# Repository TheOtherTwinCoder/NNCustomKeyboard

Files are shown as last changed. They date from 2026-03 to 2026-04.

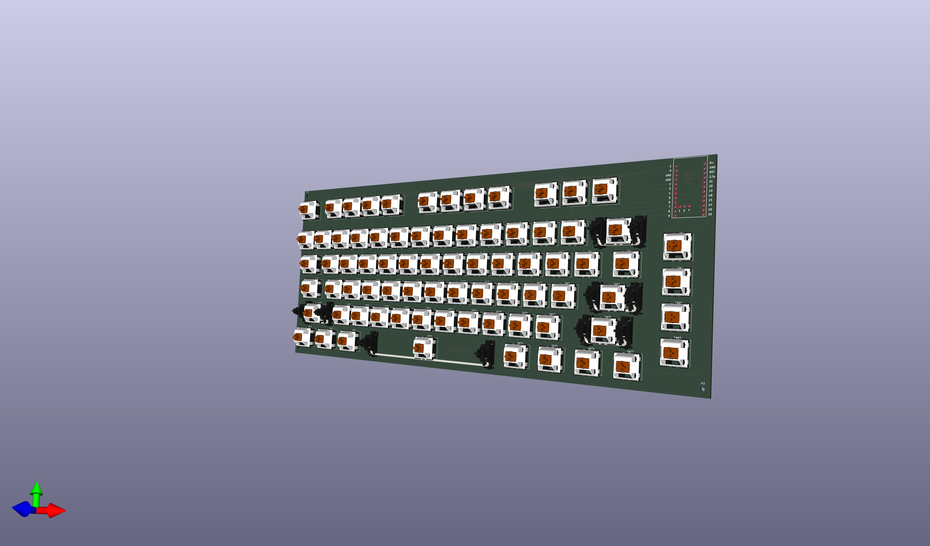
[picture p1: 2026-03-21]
3DFiles/3DPCB.png

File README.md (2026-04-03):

[Sponsored by AIVON](https://www.aivon.com/?code=K7)

# NNCustomKeyboard
I love keyboards, but they're not all that great - so let me make my own one something custom, so it's mine and something useful, so it's more practical than a traditional one!

## Look here first!

Here's my Github's sitemap:
3D Files - includes 3D file of PCB (STEP and an image), and its case

Production - includes Gerber Files, BOM, AND PNP/CPL files for PCB Fabrication

Projectfiles - includes .kicad_pcb, .kicad_sch, and .kicad_pro files to open PCB in KiCad

Links (MD file) - includes resources to build this project

README (MD file) - includes images of the PCB, the CSV file of BOM, and Assembly Instructions!

Thank you, Hack Club, AMD, Blueprint, and AIVON!

## Onshape Link

https://cad.onshape.com/documents/c9928b6a9f4ef1bbd20ca445/w/38d45bd75b935af33784f8b5/e/9c69ae00eee7f366adcabbe1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

## Full Assembly

Screenshot 2026-03-22 at 12 18 09 PM

## The V2 PCB:



## The PCB Schematic:



## Wiring Schematic

Screenshot 2026-03-16 at 1 09 35 PM

## BOM

| Items | Cost | Links | 
| :---: | :---: | :--- |
| Alpha Keys | $2.77 | (https://www.aliexpress.us/item/3256805792312994.html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) |
| PCB | $39 | Order using Gerber Files in the production folder :), this is a JLCPCB estimate, not including shipping. |
| Nice-Nano | $25 | https://typeractive.xyz/products/nice-nano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 |
| Battery | $8 | https://t.ly/81SML |
| Switches | $30 | https://mechanicalkeyboards.com/checkouts/cn/hWNA2r5NHFXzy1tke3oyGLrU/en/information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|
| Stabilizers | $1 | https://www.keychron.com/products/keychron-gold-plated-pcb-mounted-stabilizer-set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 |
| Grand Total | $138 | Submitting for review on Mar 21st!!! :) |

## Assembly

1. Since PCBA already assembled the diodes, we can skip this step. However, if no PCBA, solder on the diodes manually.
2. Solder on the AliExpress switches (found in the BOM).
3. Solder on Nice!Nano (BOM), and solder battery (BOM) to B+ and B- pins.
4. 3D Print the Case, located in STEP3D
5. Take the assembled PCB and slot it into the case
6. Solder on the rgb controller to the nice!nano, and the light strip to the controller.
7. Follow the instructions in [this video](https://www.youtube.com/watch?v=O_urj-rF3bQ)
8. That's it :)

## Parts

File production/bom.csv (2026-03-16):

Designator | Footprint | Quantity | Value | LCSC Part #
D1, D10, D11, D12, D13, D14, D15, D16, D17, D18, D19, D2, D20, D21, D22, D23, D24, D25, D26, D27, D28, D29, D3, D30, D31, D32, D33, D34, D35, D36, D37, D38, D39, D4, D40, D41, D42, D43, D44, D45, D46, D47, D48, D49, D5, D50, D51, D52, D53, D54, D55, D56, D57, D58, D59, D6, D60, D61, D62, D63, D64, D65, D66, D67, D68, D69, D7, D70, D71, D72, D73, D74, D75, D76, D77, D8, D9 | D_SOD-123F | 77 | D
SW1, SW10, SW11, SW12, SW13, SW14, SW15, SW16, SW17, SW18, SW19, SW2, SW20, SW21, SW22, SW23, SW24, SW25, SW27, SW29, SW3, SW30, SW31, SW32, SW33, SW34, SW35, SW36, SW37, SW38, SW39, SW4, SW40, SW42, SW44, SW45, SW46, SW47, SW48, SW49, SW5, SW50, SW51, SW52, SW53, SW54, SW56, SW58, SW59, SW6, SW60, SW61, SW62, SW63, SW64, SW65, SW66, SW67, SW69, SW7, SW8, SW9 | SW_Cherry_MX_PCB_1.00u | 62 | SW_Push
SW26 | SW_Cherry_MX_PCB_2.00u | 1 | SW_Push
SW28, SW41 | SW_Cherry_MX_PCB_1.50u | 2 | SW_Push
SW43 | SW_Cherry_MX_PCB_1.75u | 1 | SW_Push
SW55, SW57 | SW_Cherry_MX_PCB_2.25u | 2 | SW_Push
SW68 | SW_Cherry_MX_PCB_2.75u | 1 | SW_Push
SW70, SW71, SW72, SW74, SW75, SW76, SW77 | SW_Cherry_MX_PCB_1.25u | 7 | SW_Push
SW73 | SW_Cherry_MX_PCB_6.25u | 1 | SW_Push
U1 | Nice_Nano_V2 | 1 | Nice_Nano_V2

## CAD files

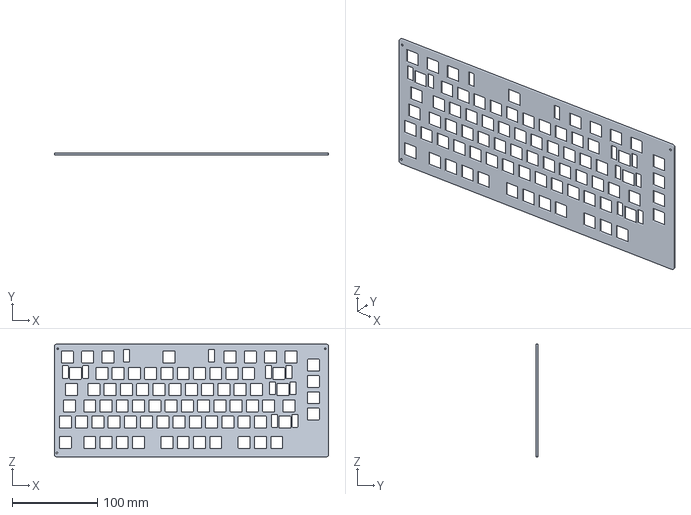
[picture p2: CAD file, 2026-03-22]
3DFiles/NewPlate.step
321.0 x 2.00 x 132.1 mm

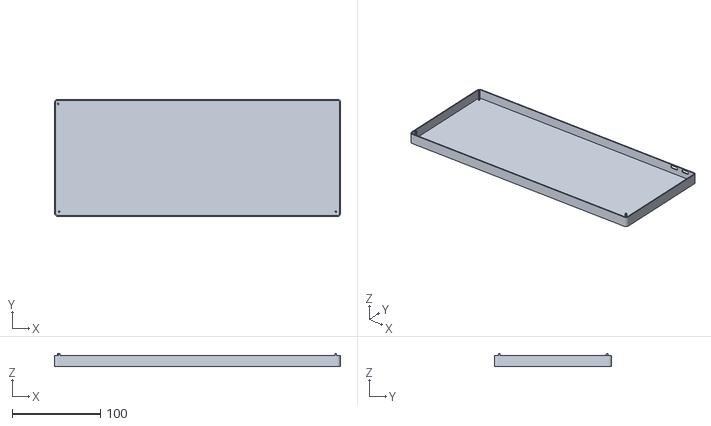
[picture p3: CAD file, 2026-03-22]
3DFiles/CaseNoPlate.stl
323.9 x 132.9 x 14.8

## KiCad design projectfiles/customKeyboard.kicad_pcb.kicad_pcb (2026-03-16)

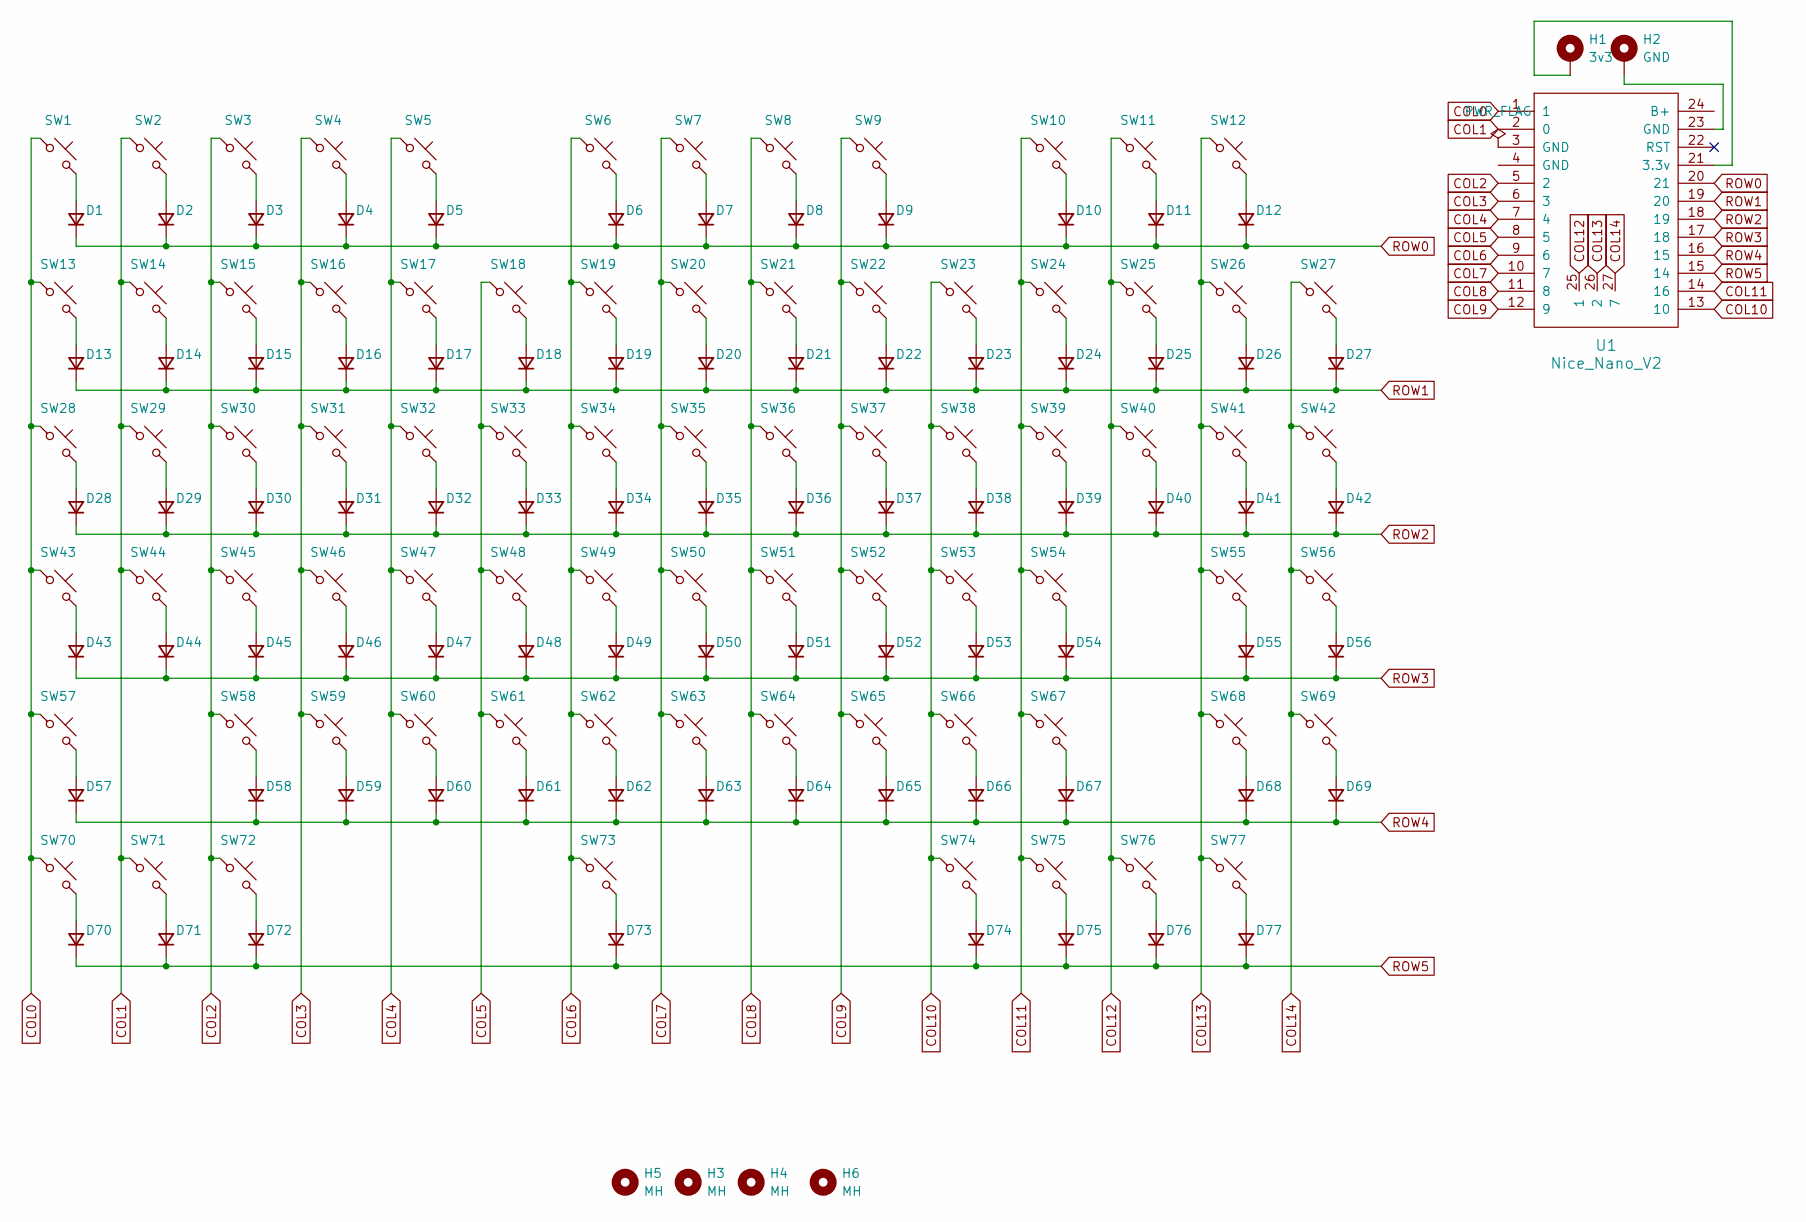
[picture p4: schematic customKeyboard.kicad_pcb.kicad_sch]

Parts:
D1, D2, D3, D4, D5, D6, D7, D8, D9, D10, D11, D12, D13, D14, D15, D16, D17, D18, D19, D20, D21, D22, D23, D24, D25, D26, D27, D28, D29, D30, D31, D32, D33, D34, D35, D36, D37, D38, D39, D40, D41, D42, D43, D44, D45, D46, D47, D48, D49, D50, D51, D52, D53, D54, D55, D56, D57, D58, D59, D60, D61, D62, D63, D64, D65, D66, D67, D68, D69, D70, D71, D72, D73, D74, D75, D76, D77: D; D_SOD-123
H1: 3v3; MountingHole_2.2mm_M2
H2: GND; MountingHole_2.2mm_M2
H3, H4, H5, H6: MH; MountingHole_2.2mm_M2
SW1, SW2, SW3, SW4, SW5, SW6, SW7, SW8, SW9, SW10, SW11, SW12, SW13, SW14, SW15, SW16, SW17, SW18, SW19, SW20, SW21, SW22, SW23, SW24, SW25, SW27, SW29, SW30, SW31, SW32, SW33, SW34, SW35, SW36, SW37, SW38, SW39, SW40, SW42, SW44, SW45, SW46, SW47, SW48, SW49, SW50, SW51, SW52, SW53, SW54, SW56, SW58, SW59, SW60, SW61, SW62, SW63, SW64, SW65, SW66, SW67, SW69: SW_Push; SW_Cherry_MX_PCB_1.00u
SW26: SW_Push; SW_Cherry_MX_PCB_2.00u
SW28, SW41: SW_Push; SW_Cherry_MX_PCB_1.50u
SW43: SW_Push; SW_Cherry_MX_PCB_1.75u
SW55, SW57: SW_Push; SW_Cherry_MX_PCB_2.25u
SW68: SW_Push; SW_Cherry_MX_PCB_2.75u
SW70, SW71, SW72, SW74, SW75, SW76, SW77: SW_Push; SW_Cherry_MX_PCB_1.25u
SW73: SW_Push; SW_Cherry_MX_PCB_6.25u
U1: Nice_Nano_V2

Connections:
COL0: SW1.1, SW13.1, SW28.1, SW43.1, SW57.1, SW70.1, U1.1
COL1: SW2.1, SW14.1, SW29.1, SW44.1, SW71.1, U1.2 (0)
COL2: SW3.1, SW15.1, SW30.1, SW45.1, SW58.1, SW72.1, U1.5 (2)
COL3: SW4.1, SW16.1, SW31.1, SW46.1, SW59.1, U1.6 (3)
COL4: SW5.1, SW17.1, SW32.1, SW47.1, SW60.1, U1.7 (4)
COL5: SW18.1, SW33.1, SW48.1, SW61.1, U1.8 (5)
COL6: SW6.1, SW19.1, SW34.1, SW49.1, SW62.1, SW73.1, U1.9 (6)
COL7: SW7.1, SW20.1, SW35.1, SW50.1, SW63.1, U1.10 (7)
COL8: SW8.1, SW21.1, SW36.1, SW51.1, SW64.1, U1.11 (8)
COL9: SW9.1, SW22.1, SW37.1, SW52.1, SW65.1, U1.12 (9)
COL10: SW23.1, SW38.1, SW53.1, SW66.1, SW74.1, U1.13 (10)
COL11: SW10.1, SW24.1, SW39.1, SW54.1, SW67.1, SW75.1, U1.14 (16)
COL12: SW11.1, SW25.1, SW40.1, SW76.1, U1.25 (1)
COL13: SW12.1, SW26.1, SW41.1, SW55.1, SW68.1, SW77.1, U1.26 (2)
COL14: SW27.1, SW42.1, SW56.1, SW69.1, U1.27 (7)
unnamed: D1.2 (A), SW1.2
unnamed: D2.2 (A), SW2.2
unnamed: D3.2 (A), SW3.2
unnamed: D4.2 (A), SW4.2
unnamed: D5.2 (A), SW5.2
unnamed: D6.2 (A), SW6.2
unnamed: D7.2 (A), SW7.2
unnamed: D8.2 (A), SW8.2
unnamed: D9.2 (A), SW9.2
unnamed: D10.2 (A), SW10.2
unnamed: D11.2 (A), SW11.2
unnamed: D12.2 (A), SW12.2
unnamed: D13.2 (A), SW13.2
unnamed: D14.2 (A), SW14.2
unnamed: D15.2 (A), SW15.2
unnamed: D16.2 (A), SW16.2
unnamed: D17.2 (A), SW17.2
unnamed: D18.2 (A), SW18.2
unnamed: D19.2 (A), SW19.2
unnamed: D20.2 (A), SW20.2
unnamed: D21.2 (A), SW21.2
unnamed: D22.2 (A), SW22.2
unnamed: D23.2 (A), SW23.2
unnamed: D24.2 (A), SW24.2
unnamed: D25.2 (A), SW25.2
unnamed: D26.2 (A), SW26.2
unnamed: D27.2 (A), SW27.2
unnamed: D28.2 (A), SW28.2
unnamed: D29.2 (A), SW29.2
unnamed: D30.2 (A), SW30.2
unnamed: D31.2 (A), SW31.2
unnamed: D32.2 (A), SW32.2
unnamed: D33.2 (A), SW33.2
unnamed: D34.2 (A), SW34.2
unnamed: D35.2 (A), SW35.2
unnamed: D36.2 (A), SW36.2
unnamed: D37.2 (A), SW37.2
unnamed: D38.2 (A), SW38.2
unnamed: D39.2 (A), SW39.2
unnamed: D40.2 (A), SW40.2
unnamed: D41.2 (A), SW41.2
unnamed: D42.2 (A), SW42.2
unnamed: D43.2 (A), SW43.2
unnamed: D44.2 (A), SW44.2
unnamed: D45.2 (A), SW45.2
unnamed: D46.2 (A), SW46.2
unnamed: D47.2 (A), SW47.2
unnamed: D48.2 (A), SW48.2
unnamed: D49.2 (A), SW49.2
unnamed: D50.2 (A), SW50.2
unnamed: D51.2 (A), SW51.2
unnamed: D52.2 (A), SW52.2
unnamed: D53.2 (A), SW53.2
unnamed: D54.2 (A), SW54.2
unnamed: D55.2 (A), SW55.2
unnamed: D56.2 (A), SW56.2
unnamed: D57.2 (A), SW57.2
unnamed: D58.2 (A), SW58.2
unnamed: D59.2 (A), SW59.2
unnamed: D60.2 (A), SW60.2
unnamed: D61.2 (A), SW61.2
unnamed: D62.2 (A), SW62.2
unnamed: D63.2 (A), SW63.2
unnamed: D64.2 (A), SW64.2
unnamed: D65.2 (A), SW65.2
unnamed: D66.2 (A), SW66.2
unnamed: D67.2 (A), SW67.2
unnamed: D68.2 (A), SW68.2
unnamed: D69.2 (A), SW69.2
unnamed: D70.2 (A), SW70.2
unnamed: D71.2 (A), SW71.2
unnamed: D72.2 (A), SW72.2
unnamed: D73.2 (A), SW73.2
unnamed: D74.2 (A), SW74.2
unnamed: D75.2 (A), SW75.2
unnamed: D76.2 (A), SW76.2
unnamed: D77.2 (A), SW77.2
unnamed: H2.1, U1.23 (GND)
unnamed: H1.1, U1.21 (3.3v)
ROW0: D1.1 (K), D2.1 (K), D3.1 (K), D4.1 (K), D5.1 (K), D6.1 (K), D7.1 (K), D8.1 (K), D9.1 (K), D10.1 (K), D11.1 (K), D12.1 (K), U1.20 (21)
ROW1: D13.1 (K), D14.1 (K), D15.1 (K), D16.1 (K), D17.1 (K), D18.1 (K), D19.1 (K), D20.1 (K), D21.1 (K), D22.1 (K), D23.1 (K), D24.1 (K), D25.1 (K), D26.1 (K), D27.1 (K), U1.19 (20)
ROW2: D28.1 (K), D29.1 (K), D30.1 (K), D31.1 (K), D32.1 (K), D33.1 (K), D34.1 (K), D35.1 (K), D36.1 (K), D37.1 (K), D38.1 (K), D39.1 (K), D40.1 (K), D41.1 (K), D42.1 (K), U1.18 (19)
ROW3: D43.1 (K), D44.1 (K), D45.1 (K), D46.1 (K), D47.1 (K), D48.1 (K), D49.1 (K), D50.1 (K), D51.1 (K), D52.1 (K), D53.1 (K), D54.1 (K), D55.1 (K), D56.1 (K), U1.17 (18)
ROW4: D57.1 (K), D58.1 (K), D59.1 (K), D60.1 (K), D61.1 (K), D62.1 (K), D63.1 (K), D64.1 (K), D65.1 (K), D66.1 (K), D67.1 (K), D68.1 (K), D69.1 (K), U1.16 (15)
ROW5: D70.1 (K), D71.1 (K), D72.1 (K), D73.1 (K), D74.1 (K), D75.1 (K), D76.1 (K), D77.1 (K), U1.15 (14)

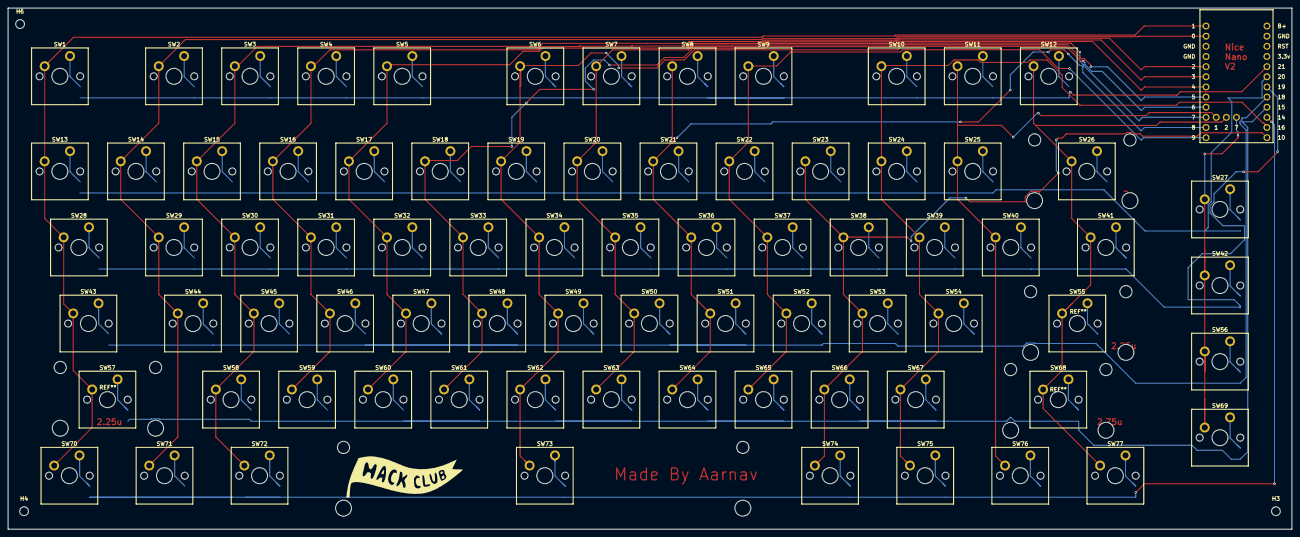
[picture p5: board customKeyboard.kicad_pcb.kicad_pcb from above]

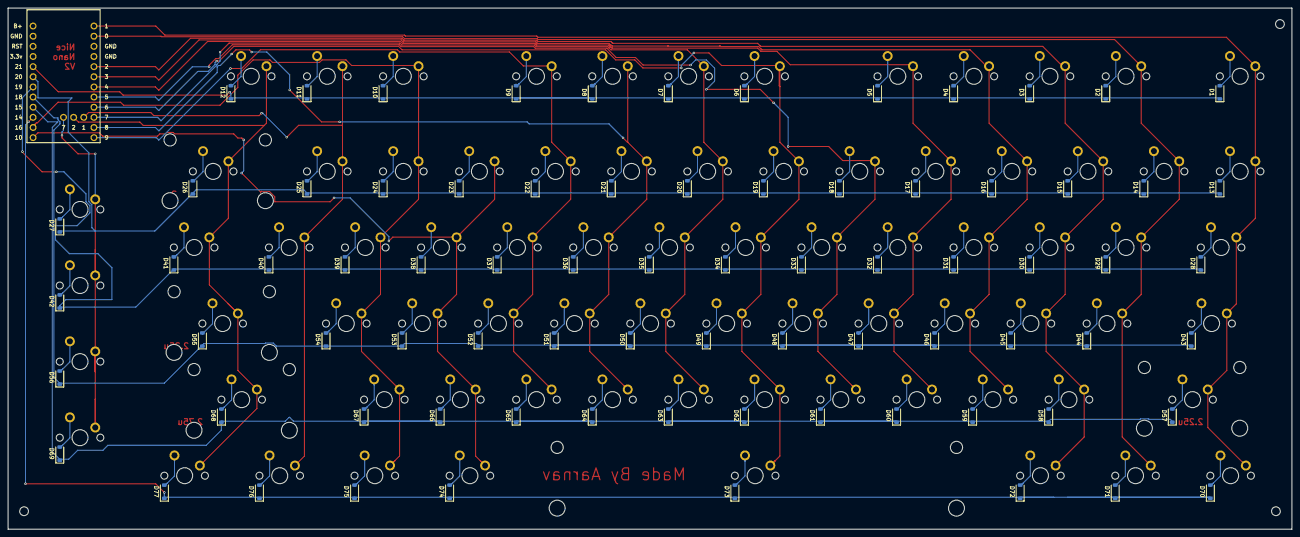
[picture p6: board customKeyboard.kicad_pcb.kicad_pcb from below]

Board: 2 copper layers, 321.5 x 130.5 mm, 158 parts (77 on the bottom side), 98 nets.

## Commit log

2026-03-21 New Case
    [customKeyboardwithUSB.stl]
2026-03-21 PCB 3D File Image
2026-03-21 Adding Assembly + Renames
    [customKeyboardwithUSB.stl]
